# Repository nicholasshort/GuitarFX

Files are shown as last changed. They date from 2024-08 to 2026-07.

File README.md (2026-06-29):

# GuitarFX

This is a digital guitar effects pedal designed as a generic DSP platform. I've written simple algorithms such as volume and tone control, however plans are in the works for others: namely hard and soft clipping, digital delay, and much more. The two knobs control various parameters within the current algorithm, including volume or cutoff frequency.

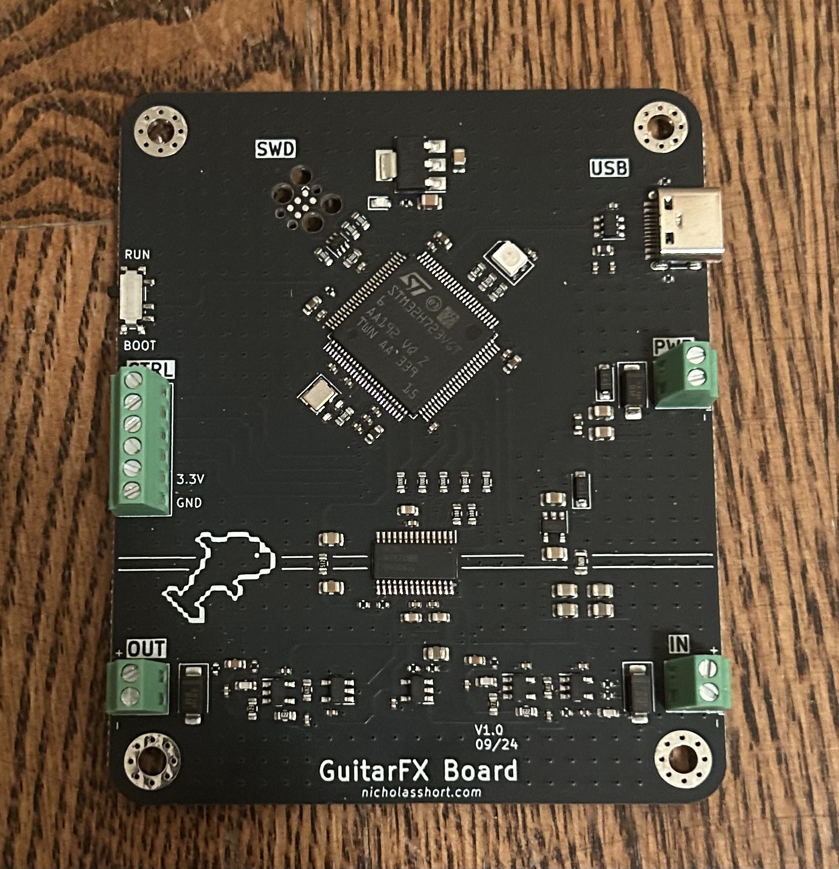
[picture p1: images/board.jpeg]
Assembled board

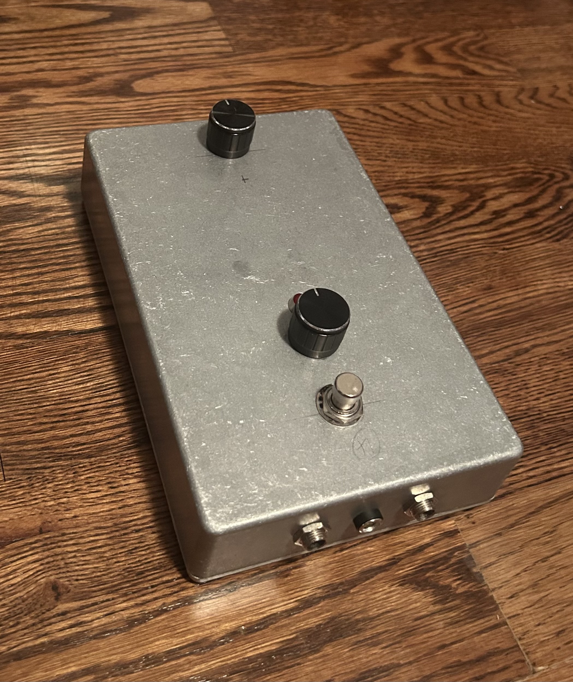
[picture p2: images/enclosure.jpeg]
Enclosure


## Hardware

- **MCU**: STM32H723VGT6 (Cortex-M7 @ 550 MHz)
- **Codec**: TI PCM3060 — 24-bit stereo ADC/DAC
- **Analog I/O**: TLV9161 op-amp buffers with 25 kHz Butterworth anti-aliasing and reconstruction filters
- **Audio**: Standard 1/4" guitar input and output, true-bypass footswitch
- **Controls**: 2 × potentiometers, RGB status LED
- **Power**: 9 V DC barrel jack (USB-C can also power the board for bench work)
- **PCB**: 4-layer, KiCad

## Repository layout

- `GuitarFX-PCB/` — KiCad project (schematics, board, libraries)
- `GuitarFX-PCB/Manufacturing/` — Gerbers, BOM, and pick-and-place files for JLCPCB
- `images/` — Photos of the board and enclosure

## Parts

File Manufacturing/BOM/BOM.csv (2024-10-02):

Comment | Designator | Footprint | JLCPCB Part #
47uF Unpolarized capacitor | C201,C202,C203,C204 | C_0805_2012Metric | C108659
2.2uF Unpolarized capacitor | C205,C206,C207,C208,C411,C412 | C_0805_2012Metric | C77081
10uF Unpolarized capacitor | C209,C210 | C_0805_2012Metric | C90543
2.2u Unpolarized capacitor | C301,C318,C319 | C_0603_1608Metric | C71001
100n Unpolarized capacitor | C302,C303,C304,C305,C306,C307,C308,C309,C310,C311,C312,C313,C316,C317,C402,C403,C404,C420,C421,C429,C431,C433 | C_0402_1005Metric | C432917
10p Unpolarized capacitor | C314,C315 | C_0402_1005Metric | C258501
1n Unpolarized capacitor | C401,C409,C419,C423 | C_0402_1005Metric | C106205
22u Unpolarized capacitor | C405 | C_0805_2012Metric | C129303
10n Unpolarized capacitor | C406 | C_0402_1005Metric | C386111
4.7u Unpolarized capacitor | C407,C422 | C_0603_1608Metric | C77045
150p Unpolarized capacitor | C408,C410,C424 | C_0603_1608Metric | C126577
10u Unpolarized capacitor | C428,C430,C432 | C_0603_1608Metric | C380314
MBR0530 30V 0.5A Schottky Power Rectifier Diode, SOD-123 | D201,D202 | D_SOD-123 | C77336
SMAJ15A 400W unidirectional Transient Voltage Suppressor, 15.0Vr, SMA(DO-214AC) | D203,D401,D403 | D_SMA | C908769
LED Light emitting diode | D204 | LED_0603_1608Metric | C5123548
PESD3V3L5UY Low capacitance unidirectional fivefold ESD protection diode array, 3.3V, Common Anode, SOT-363 | D302 | SOT-363_SC-70-6 | C3021133
LED_RGBA RGB LED, red/green/blue/anode | D303 | LED_SMD_RGB_AAA3528LSEEZGKQBKS | C5547384
120R Ferrite bead | FB201,FB301,FB302 | L_0603_1608Metric | C12391
ACM2012-900-2P-TL002 Common Mode Chokes / Filters - | FL301 | ACM20129002PTL002 | C3211819
PCM3060PWR 24-bit Asynchronous Stereo Audio Codec with 96/192kHz sampling rate | IC401 | SOP65P640X120-28N | C2651841
Screw_Terminal_01x02 Generic screw terminal, single row, 01x02, script generated (kicad-library-utils/schlib/autogen/connector/) | J202,J401,J402 | TerminalBlock_Phoenix_MPT-0,5-2-2.54_1x02_P2.54mm_Horizontal | C3029316
USB_C_Receptacle_USB2.0 USB 2.0-only Type-C Receptacle connector | J301 | USB_C_Receptacle_HRO_TYPE-C-31-M-12 | C165948
Screw_Terminal_01x06 Generic screw terminal, single row, 01x06, script generated (kicad-library-utils/schlib/autogen/connector/) | J303 | TerminalBlock_Phoenix_MPT-0,5-6-2.54_1x06_P2.54mm_Horizontal | C3817456
10R Resistor | R201 | R_0805_2012Metric | C17415
1k Resistor | R202,R401,R403,R404 | R_0402_1005Metric | C102758
10k Resistor | R301,R427,R429 | R_0402_1005Metric | C176114
33R Resistor | R302,R305,R306,R307,R308,R419,R420,R424,R426,R428 | R_0603_1608Metric | C103557
5.1k Resistor | R303,R304 | R_0402_1005Metric | C325521
325R (300R) Resistor | R309,R310 | R_0603_1608Metric | C137637
750R Resistor | R311 | R_0603_1608Metric | C328375
1M Resistor | R402,R409 | R_0402_1005Metric | C409676
8.2k Resistor | R405,R421 | R_0603_1608Metric | C103830
27k Resistor | R406,R422 | R_0603_1608Metric | C116691
15k Resistor | R407,R423 | R_0603_1608Metric | C136588
100R Resistor | R408,R425 | R_0402_1005Metric | C279985
100k Resistor | R410 | R_0402_1005Metric | C192169
5.1k Resistor | R411 | R_0603_1608Metric | C318133
10k Resistor | R417,R418 | R_0603_1608Metric | C103210
SW_SPDT Switch, single pole double throw | SW301 | SW_SPDT_PCM12 | C221841
NCP718xSN500 300-mA, Wide Input Voltage, Low-IQ LDO, 5.0V, SOT-23 | U201 | SOT-23-5 | C892796
NCP1117-3.3_SOT223 1A Low drop-out regulator, Fixed Output 3.3V, SOT-223 | U202 | SOT-223-3_TabPin2 | C26537
USBLC6-2SC6 Very low capacitance ESD protection diode, 2 data-line, SOT-23-6 | U301 | SOT-23-6 | C5261088
STM32H733VGTx STMicroelectronics Arm Cortex-M7 MCU, 1024KB flash, 564KB RAM, 550 MHz, 1.71-3.6V, 82 GPIO, LQFP100 | U302 | LQFP-100_14x14mm_P0.5mm | C730160
TLV9161IDBVR Operational Amplifiers - Op Amps Single 10-MHz, 16-V rail-to-rail input/output, very low noise, high slew rate op amp | U401,U402,U403,U406,U407 | SOT95P280X145-5N | C4368955
24MHz Four pin crystal, GND on pins 2 and 4 | Y301 | Crystal_SMD_3225-4Pin_3.2x2.5mm | C5308005

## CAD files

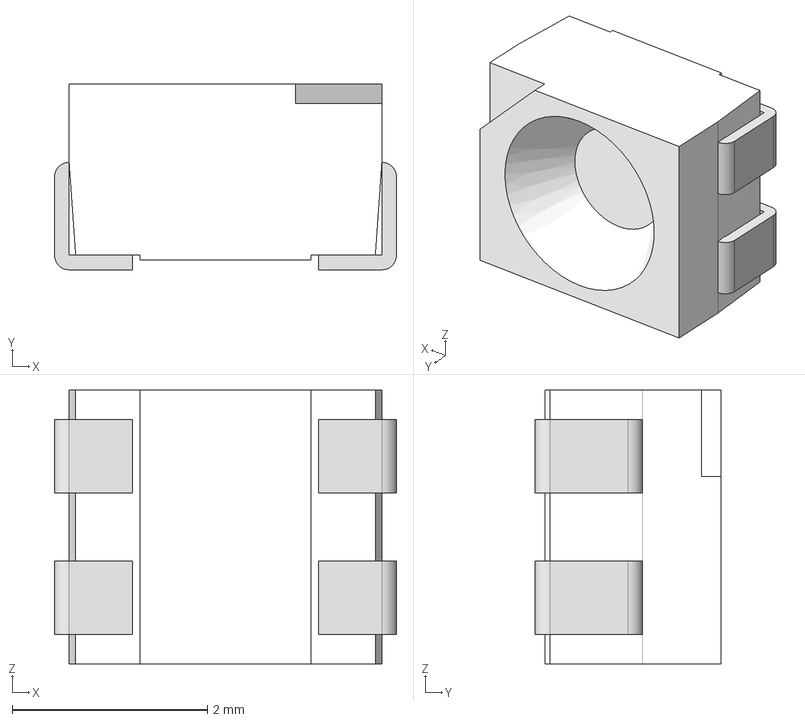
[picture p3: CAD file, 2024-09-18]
GuitarFX-PCB/Components/LIB_AAA3528LSEEZGKQBKS/AAA3528LSEEZGKQBKS/3D/AAA3528LSEEZGKQBKS.stp
3.50 x 1.90 x 2.80 mm

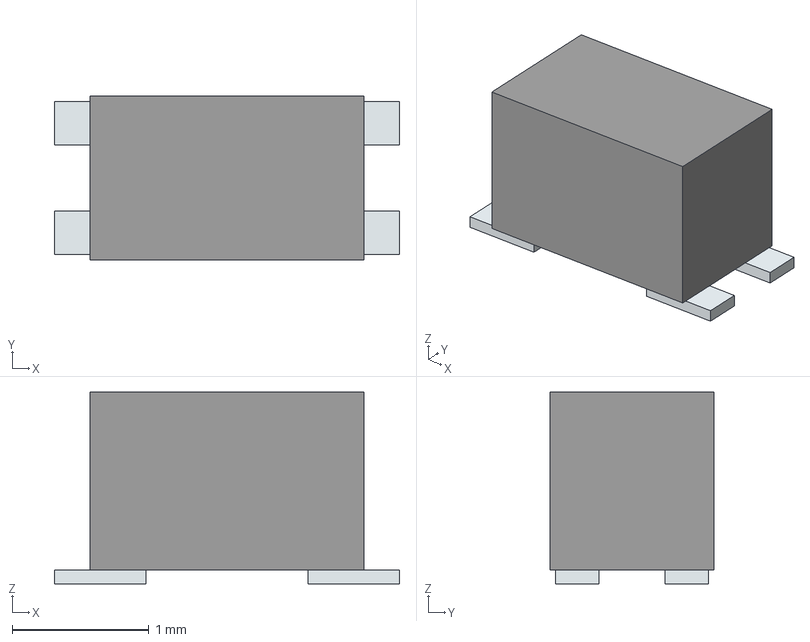
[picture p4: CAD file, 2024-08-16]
GuitarFX-PCB/Components/LIB_ACM2012-900-2P-TL002/ACM2012-900-2P-TL002/3D/ACM2012-900-2P-TL002.stp
2.52 x 1.20 x 1.40 mm
Pins

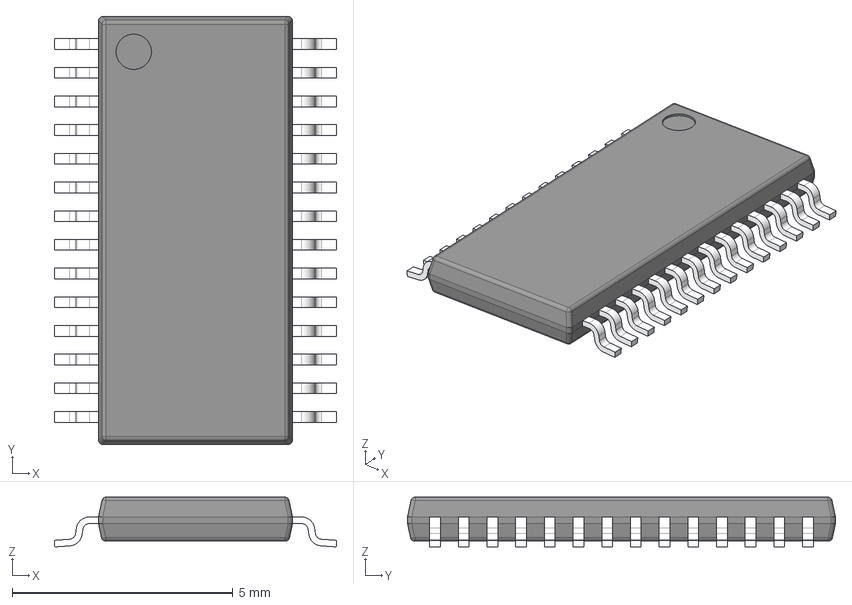
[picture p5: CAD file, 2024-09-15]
GuitarFX-PCB/Components/LIB_PCM3060PWR/PCM3060PWR/3D/PCM3060PWR.stp
6.40 x 9.70 x 1.13 mm
BODY-TSSOP
LEAD-TSSOP x 28
PIN1

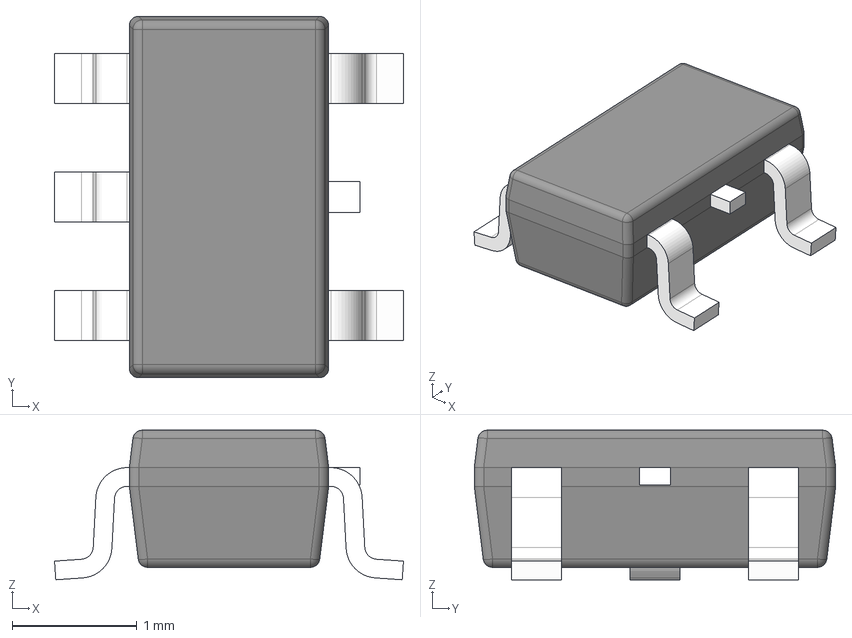
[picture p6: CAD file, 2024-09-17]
GuitarFX-PCB/Components/LIB_TLV9161IDBVR/TLV9161IDBVR/3D/TLV9161IDBVR.stp
2.80 x 2.90 x 1.20 mm
BODY-SOT
LEAD-SOT x 5
LEAD-DUMMY

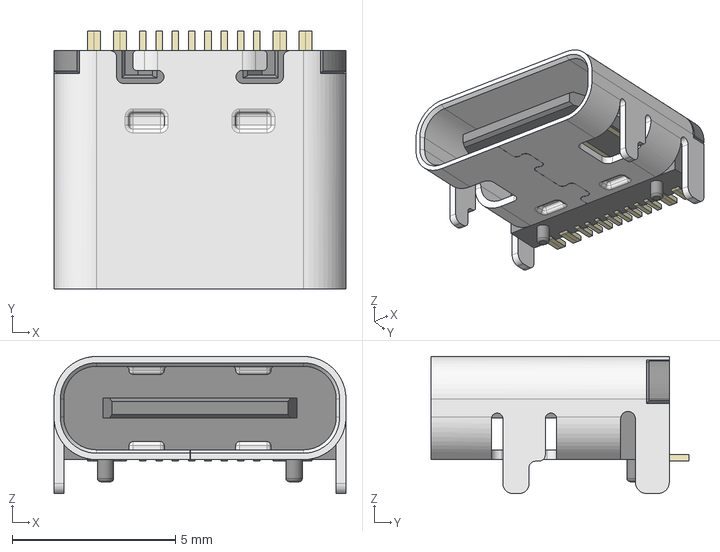
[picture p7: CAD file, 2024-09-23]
GuitarFX-PCB/Misc 3D Models/HRO_TYPE-C-31-M-12.step
8.95 x 7.90 x 4.20 mm

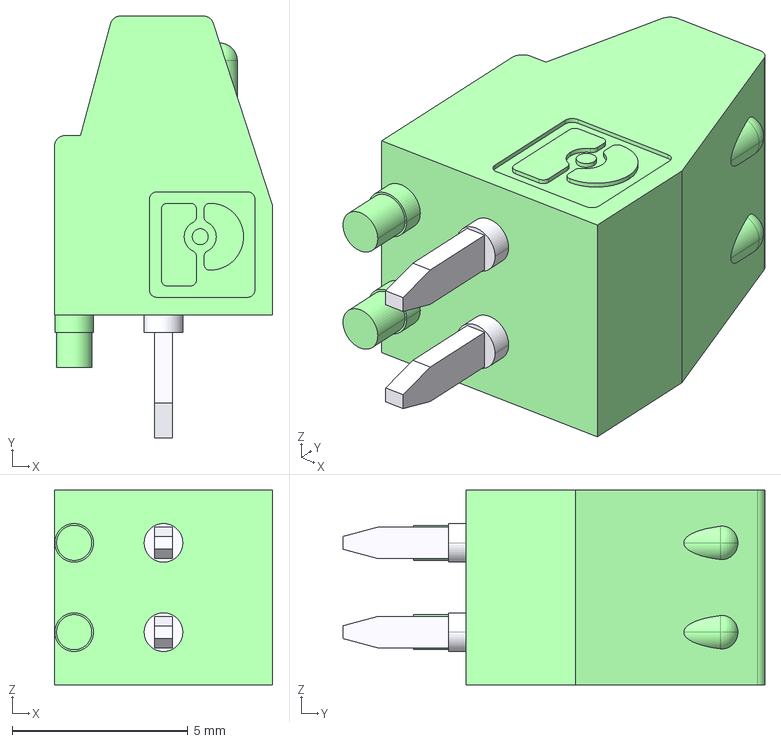
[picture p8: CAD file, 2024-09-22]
GuitarFX-PCB/Components/LIB_1725656/1725656/3D/1725656.stp
6.20 x 12.0 x 5.54 mm

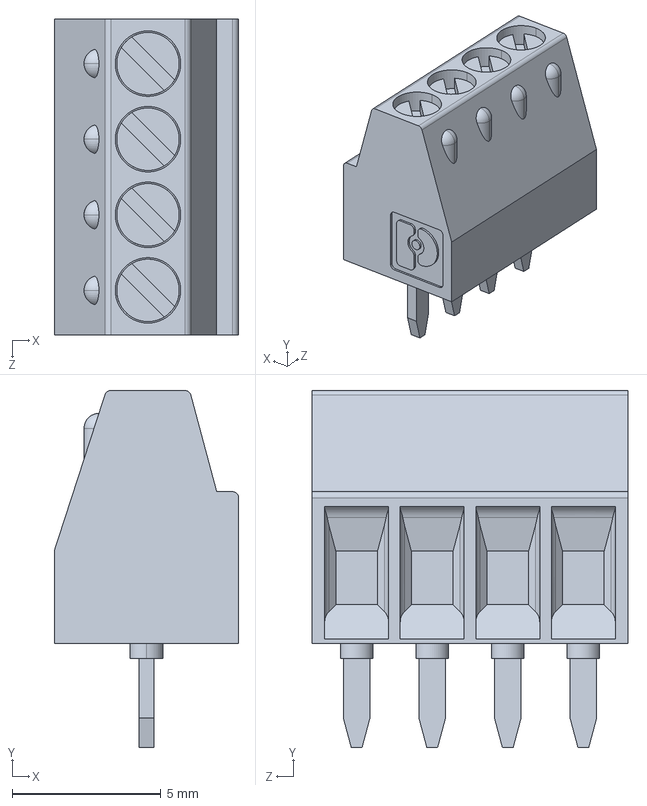
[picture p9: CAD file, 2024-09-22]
GuitarFX-PCB/Components/LIB_1725672/1725672/3D/1725672.stp
6.20 x 12.0 x 10.6 mm

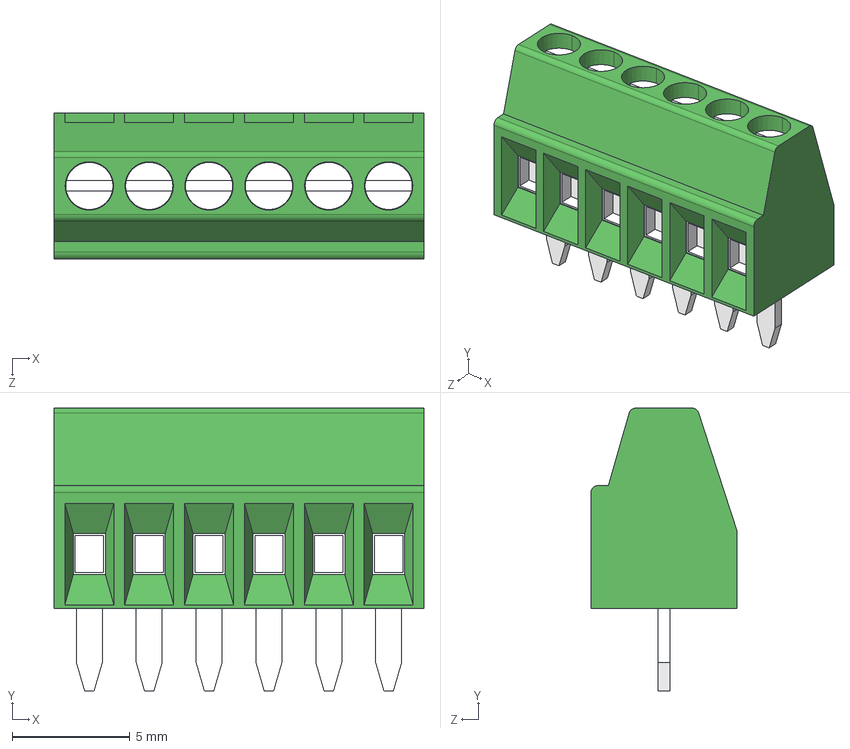
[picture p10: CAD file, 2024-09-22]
GuitarFX-PCB/Components/LIB_1725698/1725698/3D/1725698.stp
15.7 x 12.0 x 6.20 mm

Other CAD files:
GuitarFX-PCB/Components/LIB_1725656/1725656/Allegro/1725656.psm
GuitarFX-PCB/Components/LIB_1725656/1725656/DEHDL/1725656/chips/chips.prt
GuitarFX-PCB/Components/LIB_1725672/1725672/Allegro/1725672.psm
GuitarFX-PCB/Components/LIB_1725672/1725672/DEHDL/1725672/chips/chips.prt
GuitarFX-PCB/Components/LIB_1725698/1725698/Allegro/1725698.psm
GuitarFX-PCB/Components/LIB_1725698/1725698/DEHDL/1725698/chips/chips.prt
GuitarFX-PCB/Components/LIB_AAA3528LSEEZGKQBKS/AAA3528LSEEZGKQBKS/Allegro/aaa3528.psm
GuitarFX-PCB/Components/LIB_AAA3528LSEEZGKQBKS/AAA3528LSEEZGKQBKS/DEHDL/aaa3528lseezgkqbks/chips/chips.prt
GuitarFX-PCB/Components/LIB_ACM2012-900-2P-TL002/ACM2012-900-2P-TL002/Allegro/acm20129002ptl002.psm
GuitarFX-PCB/Components/LIB_ACM2012-900-2P-TL002/ACM2012-900-2P-TL002/DEHDL/acm2012_900_2p_tl002/chips/chips.prt
GuitarFX-PCB/Components/LIB_PCM3060PWR/PCM3060PWR/Allegro/sop65p640x120-28n.psm
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

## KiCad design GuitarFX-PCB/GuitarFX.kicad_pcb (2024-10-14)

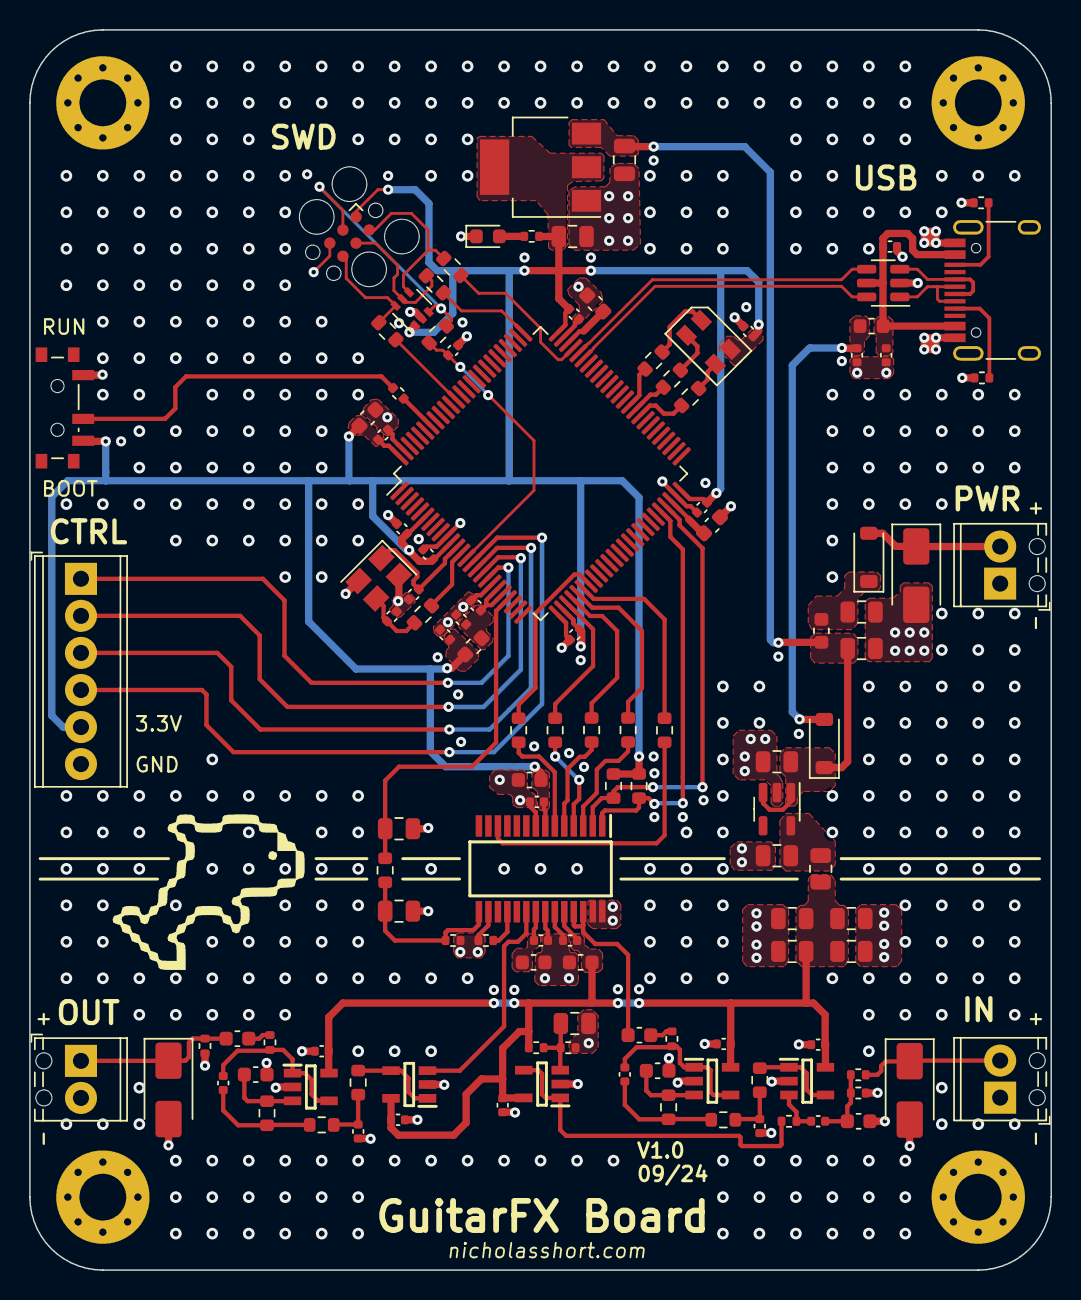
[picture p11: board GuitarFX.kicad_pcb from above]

Board: 4 copper layers, 70.0 x 85.0 mm, 123 parts (0 on the bottom side), 78 nets.

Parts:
C201, C202, C203, C204: 47uF; C_0805_2012Metric
C205, C206, C207, C208, C411, C412: 2.2uF; C_0805_2012Metric
C209, C210: 10uF; C_0805_2012Metric
C301, C318, C319: 2.2u; C_0603_1608Metric
C302, C303, C304, C305, C306, C307, C308, C309, C310, C311, C312, C313, C316, C317, C402, C403, C404, C420, C421, C429, C431, C433: 100n; C_0402_1005Metric
C314, C315: 10p; C_0402_1005Metric
C401, C409, C419, C423: 1n; C_0402_1005Metric
C405: 22u; C_0805_2012Metric
C406: 10n; C_0402_1005Metric
C407, C422: 4.7u; C_0603_1608Metric
C408, C410, C424: 150p; C_0603_1608Metric
C428, C430, C432: 10u; C_0603_1608Metric
D201, D202: MBR0530; D_SOD-123
D203, D401, D403: SMAJ15A; D_SMA
D204: LED; LED_0603_1608Metric
D302: PESD3V3L5UY; SOT-363_SC-70-6
D303: LED_RGBA; LED_SMD_RGB_AAA3528LSEEZGKQBKS
FB201, FB301, FB302: 120R; L_0603_1608Metric
H101, H102, H103, H104: MountingHole_Pad; MountingHole_3.2mm_M3_Pad_Via
IC401: PCM3060PWR; SOP65P640X120-28N
J202, J401, J402: Screw_Terminal_01x02; TerminalBlock_Phoenix_MPT-0,5-2-2.54_1x02_P2.54mm_Horizontal
J301: USB_C_Receptacle_USB2.0; USB_C_Receptacle_HRO_TYPE-C-31-M-12
J302: Conn_ARM_SWD_TagConnect_TC2030; Tag-Connect_TC2030-IDC-FP_2x03_P1.27mm_Vertical
J303: Screw_Terminal_01x06; TerminalBlock_Phoenix_MPT-0,5-6-2.54_1x06_P2.54mm_Horizontal
R201: 10R; R_0805_2012Metric
R202, R401, R403, R404: 1k; R_0402_1005Metric
R301, R427, R429: 10k; R_0402_1005Metric
R302, R305, R306, R307, R308, R419, R420, R424, R426, R428: 0R; R_0603_1608Metric
R303, R304: 5.1k; R_0402_1005Metric
R309, R310: 325R (300R); R_0603_1608Metric
R311: 750R; R_0603_1608Metric
R402, R409: 1M; R_0402_1005Metric
R405, R421: 6.8k; R_0603_1608Metric
R406, R422: 22k; R_0603_1608Metric
R407, R423: 12k; R_0603_1608Metric
R408, R425: 100R; R_0402_1005Metric
R410: 100k; R_0402_1005Metric
R411: 5.1k; R_0603_1608Metric
R417, R418: 10k; R_0603_1608Metric
SW301: SW_SPDT; SW_SPDT_PCM12
U201: NCP718xSN500; SOT-23-5
U202: NCP1117-3.3_SOT223; SOT-223-3_TabPin2
U301: USBLC6-2SC6; SOT-23-6
U303: STM32H723VGTx; LQFP-100_14x14mm_P0.5mm
U401, U402, U403, U406, U407: TLV9161IDBVR; SOT95P280X145-5N
Y301: 24MHz; Crystal_SMD_3225-4Pin_3.2x2.5mm

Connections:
+3.3V: C209.1, C301.1, C302.1, C303.1, C304.1, C305.1, C306.1, C307.1, C310.1, C317.1, C428.1, C429.1, D302.1 (K1), D303.4 (A), FB301.2, IC401.7 (VDD), J302.1 (VCC), J303.5, R202.1, R417.1, R418.1, SW301.3 (C), U202.2 (VO), U303.6 (VBAT), U303.11 (VDD), U303.27 (VDD), U303.50 (VDD), U303.75 (VDD), U303.100 (VDD)
+5V: C208.1, R201.1, U201.5 (OUT)
+5VA: C201.1, C202.1, C203.1, C204.1, C402.1, C403.1, C404.1, C420.1, C421.1, C430.1, C431.1, IC401.24 (VCC), R201.2, R401.1, U401.5 (V+), U402.5 (V+), U403.5 (V+), U406.5 (V+), U407.5 (V+)
/Codec/AUDIO_VIN: D401.1 (A1), J401.2, R404.1
/Codec/AUDIO_VOUT: C422.1, D403.1 (A1), J402.1, R427.2
/Codec/CODEC_BCK1: IC401.5 (BCK1), R424.2
/Codec/CODEC_DIN: IC401.12 (DIN), R428.2
/Codec/CODEC_DOUT: IC401.3 (DOUT), R419.2
/Codec/CODEC_LRCK1: IC401.4 (LRCK1), R420.2
/Codec/CODEC_SCK1: IC401.6 (SCKI1), R426.2
/Codec/CODEC_VCOM: C432.1, C433.1, IC401.21 (VCOM)
/Codec/CODEC_VIN: C407.1, IC401.25 (VINL), IC401.26 (VINR)
/Codec/CODEC_VOUT: IC401.20 (VOUTL+), U406.3 (+)
/Codec/IN_AA_BUFF_IN: C410.1, R407.2, U403.3 (+)
/Codec/IN_AA_BUFF_OUT: C401.1, R408.1, U403.1, U403.4 (-)
/Codec/IN_BUF_IN: C406.2, R402.1, U402.3 (+)
/Codec/IN_BUF_OUT: R405.1, U402.1, U402.4 (-)
/Codec/IN_RF: C406.1, C408.1, R404.2, R409.2
/Codec/NRST_FILT: C412.1, IC401.15 (~RST), R411.2, R429.1
/Codec/OUT_AA_BUFF_IN: C424.1, R423.2, U407.3 (+)
/Codec/OUT_AA_BUFF_OUT: C419.1, R425.1, U407.1, U407.4 (-)
/Codec/OUT_BUF_OUT: R421.1, U406.1, U406.4 (-)
/Codec/VREF: C405.1, R401.2, R403.1, U401.3 (+)
/MCU/ADC3_INP0: J303.2, U303.17 (PC2_C)
/MCU/ADC3_INP1: J303.1, U303.18 (PC3_C)
/MCU/ADC3_INP10: J303.4, U303.15 (PC0)
/MCU/ADC3_INP11: J303.3, U303.16 (PC1)
/MCU/BOOT0: R301.2, U303.94 (BOOT0)
/MCU/HSE_IN: C314.1, U303.12 (PH0), Y301.1
/MCU/HSE_OUT: R302.2, U303.13 (PH1)
/MCU/LED_B: D303.3 (BK), R309.2
/MCU/LED_G: D303.2 (GK), R310.2
/MCU/LED_R: D303.1 (RK), R311.2
/MCU/MCU_NRST: C316.1, R308.1, U303.14 (NRST)
/MCU/MCU_SWCLK: R306.1, U303.76 (PA14(JTCK)
/MCU/MCU_SWDIO: R305.1, U303.72 (PA13(JTMS)
/MCU/MCU_SWO: R307.1, U303.89 (PB3(JTDO)
/MCU/MCU_VCAP1: C318.1, U303.48 (VCAP)
/MCU/MCU_VCAP2: C319.1, U303.73 (VCAP)
/MCU/NRST: D302.3 (K2), J302.3 (~RESET), R308.2
/MCU/SWCLK: D302.5 (K4), J302.4 (SWCLK), R306.2
/MCU/SWDIO: D302.4 (K3), J302.2 (SWDIO), R305.2
/MCU/SWO: D302.6 (K5), J302.6 (SWO), R307.2
/MCU/TIM4_CH1: R309.1, U303.59 (PD12)
/MCU/TIM4_CH2: R310.1, U303.60 (PD13)
/MCU/TIM4_CH3: R311.1, U303.61 (PD14)
/MCU/USB_CON_CC1: J301.A5 (CC1), R303.1
/MCU/USB_CON_CC2: J301.B5 (CC2), R304.1
/MCU/USB_CON_D+: J301.A6 (D+), J301.B6 (D+), U301.3 (I/O2)
/MCU/USB_CON_D-: J301.A7 (D-), J301.B7 (D-), U301.1 (I/O1)
/MCU/USB_FS_D+: U301.4 (I/O2), U303.71 (PA12)
/MCU/USB_FS_D-: U301.6 (I/O1), U303.70 (PA11)
/Power/R_LED: D204.2 (A), R202.2
/Power/VCC_FILT: C206.1, C207.1, C210.1, D201.1 (K), FB201.2, U201.1 (IN), U201.3 (EN), U202.3 (VI)
/Power/VCC_RP: C205.1, D202.1 (K), FB201.1
CODEC_NRST: C411.1, R411.1, U303.22 (PA0)
GND: C201.2, C202.2, C203.2, C204.2, C205.2, C206.2, C207.2, C208.2, C209.2, C210.2, C301.2, C302.2, C303.2, C304.2, C305.2, C306.2, C307.2, C308.2, C309.2, C310.2, C311.2, C312.2, C313.2, C314.2, C315.2, C316.2, C317.2, C318.2, C319.2, C402.2, C403.2, C404.2, C405.2, C408.2, C409.2, C410.2, C411.2, C412.2, C420.2, C421.2, C423.2, C424.2, C428.2, C429.2, C430.2, C431.2, C432.2, C433.2, D203.2 (A2), D204.1 (K), D302.2 (A), D401.2 (A2), D403.2 (A2), H101.1, H102.1, H103.1, H104.1, IC401.8 (DGND), IC401.16 (SGND), IC401.22 (AGND2), IC401.23 (AGND1), IC401.27 (~MS/ADR/IFMD), IC401.28 (MODE), J202.1, J301.A1 (GND), J301.A12 (GND), J301.B1 (GND), J301.B12 (GND), J302.5 (GND), J303.6, J401.1, J402.2, R303.2, R304.2, R403.2, R409.1, R410.2, R427.1, R429.2, SW301.1 (A), U201.2 (GND), U202.1 (GND), U301.2 (GND), U303.10 (VSS), U303.19 (VSSA), U303.26 (VSS), U303.49 (VSS), U303.74 (VSS), U303.99 (VSS), U401.2 (V-), U402.2 (V-), U403.2 (V-), U406.2 (V-), U407.2 (V-), Y301.2, Y301.4
I2C1_SCL: IC401.1 (MC/SCL/FMT), R417.2, U303.46 (PB10)
I2C1_SDA: IC401.2 (MD/SDA/DEMP), R418.2, U303.47 (PB11)
I2S1_CK: R424.1, U303.29 (PA5)
I2S1_MCK: R426.1, U303.32 (PC4)
I2S1_SDI: R419.1, U303.30 (PA6)
I2S1_SDO: R428.1, U303.31 (PA7)
I2S1_WS: R420.1, U303.28 (PA4)
unnamed: C315.1, R302.1, Y301.3
unnamed: C401.2, R406.2, R407.1
unnamed: C407.2, R408.2
unnamed: C409.1, R405.2, R406.1
unnamed: C419.2, R422.2, R423.1
unnamed: C422.2, R425.2
unnamed: C423.1, R421.2, R422.1
unnamed: IC401.18 (VOUTR+), R410.1
unnamed: R301.1, SW301.2 (B)
VBUS: C311.1, C313.1, FB302.1, J301.A4 (VBUS), J301.A9 (VBUS), J301.B4 (VBUS), J301.B9 (VBUS), U301.5 (VBUS)
VCC: D202.2 (A), D203.1 (A1), J202.2
VCOM: R402.2, U401.1, U401.4 (-)
VDDA: C308.1, C309.1, FB301.1, U303.20 (VREF+), U303.21 (VDDA)
VUSB_FILT: C312.1, D201.2 (A), FB302.2

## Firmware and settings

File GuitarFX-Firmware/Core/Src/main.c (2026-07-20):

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
/* Includes ------------------------------------------------------------------*/
#include "main.h"
#include "dma.h"
#include "i2c.h"
#include "i2s.h"
#include "tim.h"
#include "gpio.h"

/* USER CODE BEGIN Includes */
#include "PCM3060-Codec.h"
#include "audio_stream.h"
#include "audio_process.h"
#include "gain.h"
#include "delay.h"

#include <stddef.h>
/* USER CODE END Includes */


void SystemClock_Config(void);
static void MPU_Config(void);
/**
  * @brief  The application entry point.
  * @retval int
  */
int main(void)
{

  /* MPU Configuration--------------------------------------------------------*/
  MPU_Config();

  /* MCU Configuration--------------------------------------------------------*/

  /* Reset of all peripherals, Initializes the Flash interface and the Systick. */
  HAL_Init();

  /* Configure the system clock */
  SystemClock_Config();

  /* Initialize all configured peripherals */
  MX_GPIO_Init();
  MX_DMA_Init();
  MX_I2S1_Init();
  MX_I2C2_Init();
  MX_TIM4_Init();
  /* USER CODE BEGIN 2 */
  PCM3060_Init();
  audio_stream_init();
  /* USER CODE END 2 */

  /* Infinite loop */
  /* USER CODE BEGIN WHILE */
  delay_effect_t delay_effect = {
    .process = delay_process,
    .reset = delay_reset,
  };
  delay_init();

  while (1)
  { 
    audio_process_poll(delay_effect);
    /* USER CODE END WHILE */

    /* USER CODE BEGIN 3 */
  }
  /* USER CODE END 3 */
}

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
 /* MPU Configuration */

void MPU_Config(void)
{
  MPU_Region_InitTypeDef MPU_InitStruct = {0};

  /* Disables the MPU */
  HAL_MPU_Disable();

  /** Initializes and configures the Region and the memory to be protected
  */
  MPU_InitStruct.Enable = MPU_REGION_ENABLE;
  MPU_InitStruct.Number = MPU_REGION_NUMBER0;
  MPU_InitStruct.BaseAddress = 0x0;
  MPU_InitStruct.Size = MPU_REGION_SIZE_4GB;
  MPU_InitStruct.SubRegionDisable = 0x87;
  MPU_InitStruct.TypeExtField = MPU_TEX_LEVEL0;
  MPU_InitStruct.AccessPermission = MPU_REGION_NO_ACCESS;
  MPU_InitStruct.DisableExec = MPU_INSTRUCTION_ACCESS_DISABLE;
  MPU_InitStruct.IsShareable = MPU_ACCESS_SHAREABLE;
  MPU_InitStruct.IsCacheable = MPU_ACCESS_NOT_CACHEABLE;
  MPU_InitStruct.IsBufferable = MPU_ACCESS_NOT_BUFFERABLE;

  HAL_MPU_ConfigRegion(&MPU_InitStruct);
  /* Enables the MPU */
  HAL_MPU_Enable(MPU_PRIVILEGED_DEFAULT);

}

/**
  * @brief  This function is executed in case of error occurrence.
  * @retval None
  */
void Error_Handler(void)
{
  /* USER CODE BEGIN Error_Handler_Debug */
  /* User can add his own implementation to report the HAL error return state */
  __disable_irq();
  while (1)
  {
  }
  /* USER CODE END Error_Handler_Debug */
}
#ifdef USE_FULL_ASSERT
/**
  * @brief  Reports the name of the source file and the source line number
  *         where the assert_param error has occurred.
  * @param  file: pointer to the source file name
  * @param  line: assert_param error line source number
  * @retval None
  */
void assert_failed(uint8_t *file, uint32_t line)
{
  /* USER CODE BEGIN 6 */
  /* User can add his own implementation to report the file name and line number,
     ex: printf("Wrong parameters value: file %s on line %d\r\n", file, line) */
  /* USER CODE END 6 */
}
#endif /* USE_FULL_ASSERT */

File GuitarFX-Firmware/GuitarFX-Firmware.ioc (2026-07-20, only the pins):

Mcu.UserName=STM32H723VGTx
PA0.GPIO_Label=CODEC_NRST
PA0.Signal=GPIO_Output
PA13(JTMS/SWDIO).Signal=DEBUG_JTMS-SWDIO
PA14(JTCK/SWCLK).Signal=DEBUG_JTCK-SWCLK
PA4.Signal=I2S1_WS
PA5.Signal=I2S1_CK
PA6.Signal=I2S1_SDI
PA7.Signal=I2S1_SDO
PB10.Signal=I2C2_SCL
PB11.Signal=I2C2_SDA
PB3(JTDO/TRACESWO).Signal=DEBUG_JTDO-SWO
PC4.Signal=I2S1_MCK
PD12.Signal=S_TIM4_CH1
PD13.Signal=S_TIM4_CH2
PD14.Signal=S_TIM4_CH3
PH0-OSC_IN.Signal=RCC_OSC_IN
PH1-OSC_OUT.Signal=RCC_OSC_OUT

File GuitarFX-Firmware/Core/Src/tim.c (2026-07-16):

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
/* Includes ------------------------------------------------------------------*/
#include "tim.h"

TIM_HandleTypeDef htim4;

/* TIM4 init function */
void MX_TIM4_Init(void)
{

  TIM_MasterConfigTypeDef sMasterConfig = {0};
  TIM_OC_InitTypeDef sConfigOC = {0};

  htim4.Instance = TIM4;
  htim4.Init.Prescaler = 0;
  htim4.Init.CounterMode = TIM_COUNTERMODE_UP;
  htim4.Init.Period = 1000-1;
  htim4.Init.ClockDivision = TIM_CLOCKDIVISION_DIV1;
  htim4.Init.AutoReloadPreload = TIM_AUTORELOAD_PRELOAD_DISABLE;
  if (HAL_TIM_PWM_Init(&htim4) != HAL_OK)
  {
    Error_Handler();
  }
  sMasterConfig.MasterOutputTrigger = TIM_TRGO_RESET;
  sMasterConfig.MasterSlaveMode = TIM_MASTERSLAVEMODE_DISABLE;
  if (HAL_TIMEx_MasterConfigSynchronization(&htim4, &sMasterConfig) != HAL_OK)
  {
    Error_Handler();
  }
  sConfigOC.OCMode = TIM_OCMODE_PWM1;
  sConfigOC.Pulse = 0;
  sConfigOC.OCPolarity = TIM_OCPOLARITY_HIGH;
  sConfigOC.OCFastMode = TIM_OCFAST_DISABLE;
  if (HAL_TIM_PWM_ConfigChannel(&htim4, &sConfigOC, TIM_CHANNEL_1) != HAL_OK)
  {
    Error_Handler();
  }
  if (HAL_TIM_PWM_ConfigChannel(&htim4, &sConfigOC, TIM_CHANNEL_2) != HAL_OK)
  {
    Error_Handler();
  }
  if (HAL_TIM_PWM_ConfigChannel(&htim4, &sConfigOC, TIM_CHANNEL_3) != HAL_OK)
  {
    Error_Handler();
  }
  HAL_TIM_MspPostInit(&htim4);

}

void HAL_TIM_PWM_MspInit(TIM_HandleTypeDef* tim_pwmHandle)
{

  if(tim_pwmHandle->Instance==TIM4)
  {
    /* TIM4 clock enable */
    __HAL_RCC_TIM4_CLK_ENABLE();
  }
}
void HAL_TIM_MspPostInit(TIM_HandleTypeDef* timHandle)
{

  GPIO_InitTypeDef GPIO_InitStruct = {0};
  if(timHandle->Instance==TIM4)
  {
    __HAL_RCC_GPIOD_CLK_ENABLE();
    /**TIM4 GPIO Configuration
    PD12     ------> TIM4_CH1
    PD13     ------> TIM4_CH2
    PD14     ------> TIM4_CH3
    */
    GPIO_InitStruct.Pin = GPIO_PIN_12|GPIO_PIN_13|GPIO_PIN_14;
    GPIO_InitStruct.Mode = GPIO_MODE_AF_PP;
    GPIO_InitStruct.Pull = GPIO_NOPULL;
    GPIO_InitStruct.Speed = GPIO_SPEED_FREQ_LOW;
    GPIO_InitStruct.Alternate = GPIO_AF2_TIM4;
    HAL_GPIO_Init(GPIOD, &GPIO_InitStruct);

  }

}

void HAL_TIM_PWM_MspDeInit(TIM_HandleTypeDef* tim_pwmHandle)
{

  if(tim_pwmHandle->Instance==TIM4)
  {
    /* Peripheral clock disable */
    __HAL_RCC_TIM4_CLK_DISABLE();
  }
}



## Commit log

2024-07-19 Empty project
    [GuitarFX.kicad_pcb, GuitarFX.kicad_sch]
2024-07-25 Started power section
    [Codec.kicad_sch, GuitarFX.kicad_pcb, GuitarFX.kicad_sch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]
2024-07-26 Finished power schematic
    [Power.kicad_sch]
2024-07-26 Annotating schematic and fixing mistake
    [Power.kicad_sch]
2024-07-26 Added power led to power schematic
    [Power.kicad_sch]
2024-07-31 Added decuopling capacitors and filtering to MCU
    [GuitarFX.kicad_sch, MCU.kicad_sch, Memory.kicad_sch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]
2024-08-06 Finished crystal oscillator circuit
    [MCU.kicad_sch]
2024-08-15 Finished tag connect SWD connections on schematic
    [Codec.kicad_sch, MCU.kicad_sch]
2024-08-16 Added USB-C connector to schematic and changed inductors in filters to ferrites
    [ACM2012-900-2P-TL002.SchLib, ACM2012-900-2P-TL002.stp, ACM20129002PTL002.PcbLib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]
2024-08-24 Added decoupling caps to codec
    [Codec.kicad_sch]
2024-08-25 Finished i2s and i2c connections on codec and mcu
    [Codec.kicad_sch, MCU.kicad_sch]
2024-09-15 Added new codec: PCM3060
    [Codec.kicad_sch, EDI2CAP.CFG, PCM3060PWR.SchLib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]
2024-09-16 Added connections to CODEC
    [Codec.kicad_sch, GuitarFX.kicad_sch]
2024-09-17 Refactored CODEC and added opamp for analog front end
    [Codec.kicad_sch, EDI2CAP.CFG, SOT95P280X145-5N.PcbLib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]
2024-09-17 Added RGB LEDs and ADC connections for potentiometer readings along with connector
    [Codec.kicad_sch, MCU.kicad_sch, Power.kicad_sch]
2024-09-17 Completed Analog Frontend schematic
    [Codec.kicad_sch]
2024-09-18 Fixed capactor value on frontend
    [Codec.kicad_sch]
2024-09-18 Completed the 'Rearend' lmao
    [Codec.kicad_sch]
2024-09-18 Got rid of most ERC violations
    [Codec.kicad_sch, MCU.kicad_sch, Power.kicad_sch]
2024-09-18 Updated footprints for capacitors
    [Codec.kicad_sch, MCU.kicad_sch, Power.kicad_sch]
2024-09-18 Created RGB LED footprint
    [AAA3528LSEEZGKQBKS.stp, Codec.kicad_sch, EDI2CAP.CFG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]
2024-09-22 Assigned all footprints
    [1725656.PcbLib, 1725656.SchLib, 1725656.psm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]
2024-09-22 Fixed footprints for some components
    [Power.kicad_sch]
2024-09-22 Changed butterworth filter components to 0603 for easier resoldering
    [Codec.kicad_sch, Power.kicad_sch]
2024-09-22 Updated USBC connector part and confirmed it is on JLC
    [MCU.kicad_sch]
2024-09-22 Corrected glitched old save for footprint assignment
    [GuitarFX.kicad_pcb, Power.kicad_sch]
2024-09-23 Completed board setup
    [GuitarFX.kicad_pcb]
2024-09-23 Updating 3D models for each component
    [GuitarFX.kicad_pcb, HRO_TYPE-C-31-M-12.step]
2024-09-23 Finished rough layout for MCU
    [GuitarFX.kicad_pcb, MCU.kicad_sch]
2024-09-23 Changed to mono input, and finished rough Analog Frontend layout
    [Codec.kicad_sch, GuitarFX.kicad_pcb, Power.kicad_sch]
2024-09-25 Finished rough layout
    [Codec.kicad_sch, GuitarFX.kicad_pcb, MCU.kicad_sch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]
2024-09-25 Added mounting holes
    [GuitarFX.kicad_pcb, GuitarFX.kicad_sch]
2024-09-25 Made position changes to nicer coordinates, and added edge cuts
    [GuitarFX.kicad_pcb, MCU.kicad_sch]
2024-09-25 Pre routing commit
    [GuitarFX.kicad_pcb]
2024-09-25 Routed mcu decoupling caps and crystal
    [GuitarFX.kicad_pcb]
2024-09-25 USB routing complete
    [GuitarFX.kicad_pcb, MCU.kicad_sch]
2024-09-26 Finished routing for i2s
    [Codec.kicad_sch, GuitarFX.kicad_pcb]
2024-09-26 Updated I2C pins for easier routing
    [GuitarFX.kicad_pcb, MCU.kicad_sch]
2024-09-26 SWD routing done
    [GuitarFX.kicad_pcb, MCU.kicad_sch]
2024-09-26 RGB led routing complete
    [GuitarFX.kicad_pcb]
2024-09-26 Routing complete for ADC section
    [GuitarFX.kicad_pcb]
2024-09-27 DAC portion routed
    [GuitarFX.kicad_pcb]
2024-09-27 Finished routing LDO sections
    [GuitarFX.kicad_pcb]
2024-09-27 5VA Power routing complete
    [GuitarFX.kicad_pcb]
2024-09-27 Finished 3V power routing
    [GuitarFX.kicad_pcb, GuitarFX.kicad_sch, Power.kicad_sch]
2024-09-27 Added pi filter for Codec NRST signal
    [Codec.kicad_sch, GuitarFX.kicad_pcb]
2024-09-28 Completed ADC terminal block connections. Finished routing
    [Codec.kicad_sch, GuitarFX.kicad_pcb, MCU.kicad_sch]
2024-09-28 Fixed errors in DRC
    [GuitarFX.kicad_pcb]
2024-09-28 Added stitching vias
    [GuitarFX.kicad_pcb]
2024-09-28 Added silkscreen and tidied up component positioning
    [GuitarFX.kicad_pcb]
2024-09-29 Added JLCPCB part numbers for main hardware components to order them
    [Codec.kicad_sch, GuitarFX.kicad_sch, MCU.kicad_sch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]
2024-10-13 Updated 33R resistors to 0R and changed MCU to H723 from H733
    [Codec.kicad_sch, GuitarFX.kicad_pcb, MCU.kicad_sch]
2024-10-13 Updated butterworth fc to 25khz, and changed jlc part numbers for resitors and caps
    [Codec.kicad_sch, MCU.kicad_sch]
2024-10-14 Removed CMC and generated new production files
    [GuitarFX-B_Cu.gbr, GuitarFX-B_Mask.gbr, GuitarFX-B_Paste.gbr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]
2026-06-29 Cleaning up repo
    [1725656.PcbLib, 1725656.SchLib, 1725656.psm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]
2026-07-16 Working DMA callbacks. Need to test on guitar setup
2026-07-17 Reduced DMA buffer sizes. Audio is much less delayed. Still sucks
2026-07-17 Ensuring data sent is left aligned in 32bit frame

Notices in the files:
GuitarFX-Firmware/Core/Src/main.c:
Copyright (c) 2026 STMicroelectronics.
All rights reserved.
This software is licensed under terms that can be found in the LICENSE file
